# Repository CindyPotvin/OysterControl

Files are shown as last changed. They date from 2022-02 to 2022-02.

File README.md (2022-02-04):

# Oyster Control Arduino shield

An Arduino shield to control 3 5V devices over USB, and a 24V devices (an humidifier) to grow oyster mushrooms in a box. Includes the Kicad project with the schematic and PCB, and the Arduino sketch.

See the blog post
https://robotsbench.com/custom-arduino-uno-shield-for-growing-oyster-mushrooms/ for more details about building the shield.

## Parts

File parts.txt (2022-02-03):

Stewart Connector USB A SS-52100-001
https://www.mouser.ca/ProductDetail/530-SS-52100-001

IRL520NSTRLPBF Power mosfet
https://www.mouser.ca/ProductDetail/942-IRL520NSTRLPBF

USB LED Strips SMD3528 16watt
https://www.aliexpress.com/item/32819374484.html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,searchweb201602_,searchweb201603_

CJMCU-811 (CCS811) header 8
https://www.aliexpress.com/item/32903358923.html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,searchweb201602_,searchweb201603_

Original Xiaomi SOLOVE H3 1.5watts
https://www.aliexpress.com/item/4001149537869.html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,searchweb201602_,searchweb201603_

1pc 5V USB Connector PC Fan Cooler Heatsink Exhaust CPU Cooling Fan Replacement with 45cm Cable 50x50x10MM 0.9 w
https://www.aliexpress.com/item/4000028952429.html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,searchweb201602_,searchweb201603_

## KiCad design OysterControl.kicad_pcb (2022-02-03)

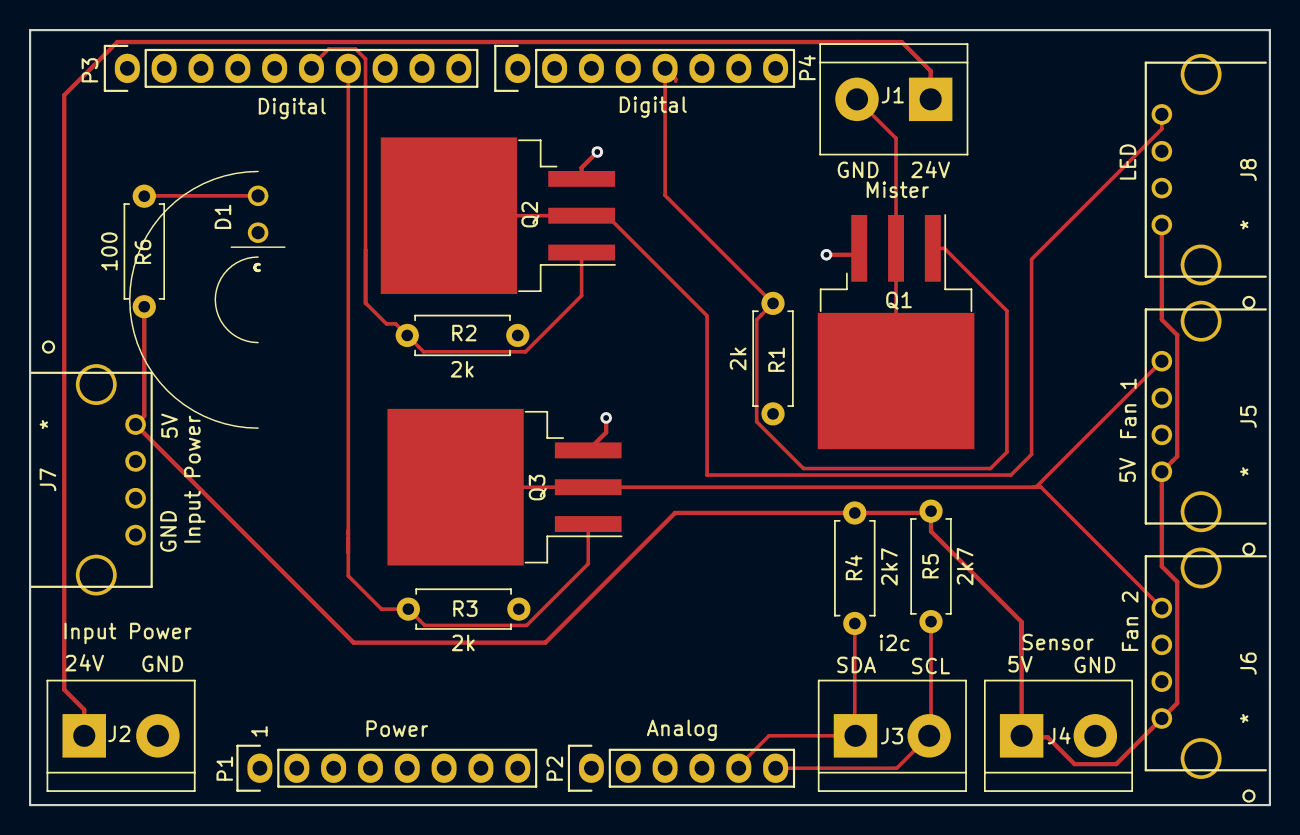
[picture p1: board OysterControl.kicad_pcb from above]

Board: 2 copper layers, 85.5 x 53.4 mm, 22 parts (0 on the bottom side), 12 nets.

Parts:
D1: LED; LTL2R3KGDEM
J1: Mister; TerminalBlock_bornier-2_P5.08mm
J2: Input Power; TerminalBlock_bornier-2_P5.08mm
J3: i2c; TerminalBlock_bornier-2_P5.08mm
J4: Sensor; TerminalBlock_bornier-2_P5.08mm
J5: Fan 1; SS-52100-001
J6: Fan 2; SS-52100-001
J7: Input Power; SS-52100-001
J8: LED; SS-52100-001
P1: Power; Socket_Strip_Arduino_1x08
P2: Analog; Socket_Strip_Arduino_1x06
P3: Digital; Socket_Strip_Arduino_1x10
P4: Digital; Socket_Strip_Arduino_1x08
Q1, Q2, Q3: IRF520NSTRLPBF; TO-263-3_TabPin2
R1, R2, R3: 2k; R_Axial_DIN0207_L6.3mm_D2.5mm_P7.62mm_Horizontal
R4, R5: 2k7; R_Axial_DIN0207_L6.3mm_D2.5mm_P7.62mm_Horizontal
R6: 100; R_Axial_DIN0207_L6.3mm_D2.5mm_P7.62mm_Horizontal

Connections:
/3(MIST): P4.5, Q1.1, R1.1
/11(FAN): P3.7, Q3.1, R3.1
/12(LED): P3.6, Q2.1, R2.1
/+5V: J4.1, J5.1, J6.1, J7.1, J8.1, R4.1, R5.1, R6.2
/+24V: J1.1, J2.1
/A4(SDA): J3.1, P2.5, R4.2
/A5(SCL): J3.2, P2.6, R5.2
GND: D1.1, J2.2, J4.2, J7.4, P1.6, P1.7, P3.4, Q1.3, Q2.3, Q3.3, R1.2, R2.2, R3.2
unnamed: D1.2, R6.1
unnamed: J1.2, Q1.2
unnamed: J5.4, J6.4, Q3.2
unnamed: J8.4, Q2.2

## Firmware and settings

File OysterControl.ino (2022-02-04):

#include <Adafruit_Sensor.h>
#include <Adafruit_BME280.h>
#include <LiquidCrystal.h>
#include <SparkFunCCS811.h>
#include <Wire.h>

// LCD pins to Arduino.
const int pin_RS = 8; 
const int pin_EN = 9; 
const int pin_d4 = 4; 
const int pin_d5 = 5; 
const int pin_d6 = 6; 
const int pin_d7 = 7; 
const int pin_BL = 10; 
// Other arduino pins
const int pin_FAN = 11; 
const int pin_LED = 12; 
const int pin_MIST = 3;
LiquidCrystal lcd( pin_RS, pin_EN, pin_d4, pin_d5, pin_d6, pin_d7);

// Default I2C address set on the board for the BME280 temperature/humidity/pressure sensor.
const int BME_I2C_ADDRESS = 0x76;
Adafruit_BME280 weatherSensor;

// Default I2C Address for the CCS811 eCO2/tVOC sensor
const int CCS811_ADDR = 0x5A; 
CCS811 co2sensor(CCS811_ADDR);

// Rate at which the loop for the display and devices runs. 
const int REFRESH_RATE_MS = 1000; 

// Fan status
bool fans = false;
// CO2 ppm at which the fans starts.
const int MAX_CO2 = 800;
// C02 ppm at which the fan closes.
const int MIN_CO2 = 600;

// Misting status
bool mister = false;
// % humidify at which the mister starts
const int MIN_HUMIDITY = 40;
// % humidify at which the mister closes.
const int MAX_HUMIDITY = 50;

void setup() {
   Serial.begin(115200);
   Serial.println("Initialization starts");
   Wire.begin();

   // CO2 sensor setup, prints error if any.
   CCS811Core::CCS811_Status_e returnCode = co2sensor.beginWithStatus(Wire);
   Serial.println("CCS811 begin exited with: ");
   Serial.println(co2sensor.statusString(returnCode));

   // Temperature and humidity sensor setup, print error if it fails.
   if (!weatherSensor.begin(BME_I2C_ADDRESS)) {
      Serial.println("Could not find the BME280 sensor, check wiring!");
   }
   
   // Light is always on in this version, so start now.
   pinMode(pin_LED, OUTPUT); 
   digitalWrite(pin_LED, HIGH);

   // Set other control pins as output and set initial values
   pinMode(pin_FAN, OUTPUT); 
   pinMode(pin_MIST, OUTPUT); 
   int co2Value = getCO2Value(&co2sensor);
   if (co2Value > MAX_CO2 && co2Value > MIN_CO2) {
      fans = true;
      digitalWrite(pin_FAN, HIGH);
   }
   else {
      fans = false;
      digitalWrite(pin_FAN, LOW);
   }

   int humidityValue = getHumidityValue(&weatherSensor);
   if (humidityValue < MIN_HUMIDITY && humidityValue < MAX_HUMIDITY) {
      mister = true;
      digitalWrite(pin_MIST, HIGH);
   }
   else {
      mister = false;
      digitalWrite(pin_MIST, LOW);
   }

   // Sets the LCD backlight at 20% brightness (analog ranges from 0 to 255).
   pinMode(pin_BL, OUTPUT);               
   analogWrite(pin_BL, 50);     
   Serial.println("Initialized");         
}

void loop() {
   // LED always on
   digitalWrite(pin_LED, HIGH);
   // First LCD line display, current sensor values.
   lcd.begin(16, 2);
   lcd.clear();
   lcd.setCursor(0,0);
   const String temperatureHumidity = getTemperatureHumidity(&weatherSensor);
   const int co2Value = getCO2Value(&co2sensor);
   const String lcdFirstLine = temperatureHumidity + " " + co2Value + "ppm";
   lcd.print(lcdFirstLine);
   Serial.println(lcdFirstLine);
   // Second LCD line display, current devices.
   lcd.setCursor(0,1);

   if (co2Value > MAX_CO2) {
      fans = true;
      digitalWrite(pin_FAN, HIGH);
   }
   else if (co2Value < MIN_CO2) {
      fans = false;
      digitalWrite(pin_FAN, LOW);
   }  

   int humidityValue = getHumidityValue(&weatherSensor);
   if (humidityValue < MIN_HUMIDITY) {
      mister = true;
      digitalWrite(pin_MIST, HIGH);
   }
   else if (humidityValue > MAX_HUMIDITY) {
      mister = false;
      digitalWrite(pin_MIST, LOW);
   }
   
   String fanLcd = "FAN";
   if (!fans) {
      fanLcd = "";
   }
   String misterLcd = "MIST";
   if (!mister) {
      misterLcd = "";
   }
   
   const String lightLcd = "LIGHT";
   String lcdSecondLine = fanLcd + " " + misterLcd + " " + lightLcd;
   lcd.print(lcdSecondLine);
   Serial.println(lcdSecondLine);

   delay(REFRESH_RATE_MS);
} 

int getHumidityValue(Adafruit_BME280* sensor) {
   float humidity = sensor->readHumidity();
   return humidity;
}


String getTemperatureHumidity(Adafruit_BME280* sensor) {
   float temperature = sensor->readTemperature();
   float humidity = sensor->readHumidity();
    
   String temperatureHumidity = String(temperature, 0);
          temperatureHumidity += "C ";
          temperatureHumidity += String(humidity, 0);
          temperatureHumidity += "%";

   return (temperatureHumidity);
}

int getCO2Value(CCS811* sensor) {
   if (sensor->dataAvailable()) {
      sensor->readAlgorithmResults();
      return sensor->getCO2();
   }
   Serial.println("No data available for CO2.");
   return 0;
}

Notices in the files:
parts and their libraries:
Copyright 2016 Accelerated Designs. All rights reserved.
